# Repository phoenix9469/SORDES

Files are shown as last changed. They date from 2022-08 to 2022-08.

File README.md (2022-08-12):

## Sordes Motherboard SMT Version
### Schematic

### PCB

### 3D Top

### 3D Bottom

### Main MCU
ESP32_WROOM_32D
Internal Antenna
### Battery Charging
TP4056 Li-Ion Battery Charging Circuit(1A)
### DC-DC
SX1308 DC-DC Step Up Convertor(1.2MHz,2A)
3.7v~4.2v(Battery) to 5v(Logic)
### Weight measurement
HX711 24-Bit ADC for Weigh Scales
## Sordes LCD Board SMT Version
### Schematic

### PCB

### 3D Top
LCD_module_top
### 3D Bottom
LCD_module_bottom
### Main MCU
ESP32_WROOM_32D
Internal Antenna
### Pinmap
3.3V -> VCC  
GND -> GND  
GPIO15 -> CS  
GPIO4 -> RESET  
GPIO2 - > DC/RS  
GPIO23 -> SDI(MOSI),T_DIN  
GPIO18 -> SCK,T_CLK  
GPIO32 -> LED  
GPIO21 -> T_CS  
GPIO19 -> T_DO  
GPIO27 -> T_IRQ

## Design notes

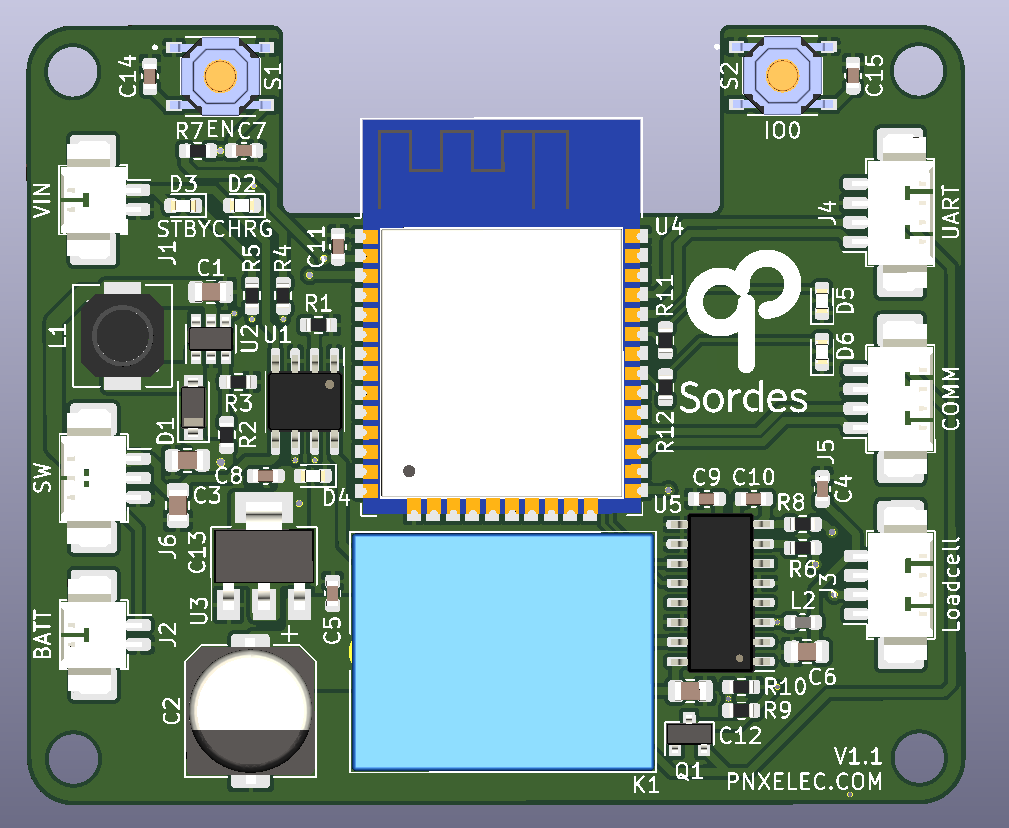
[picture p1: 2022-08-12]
Image/top.png

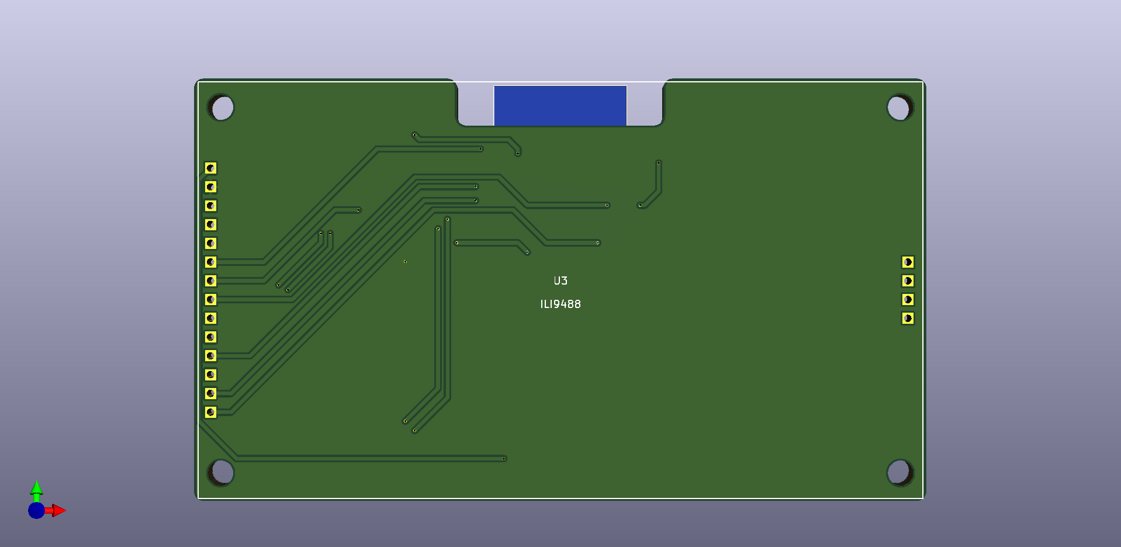
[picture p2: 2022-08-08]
Image/LCD_module_top.png

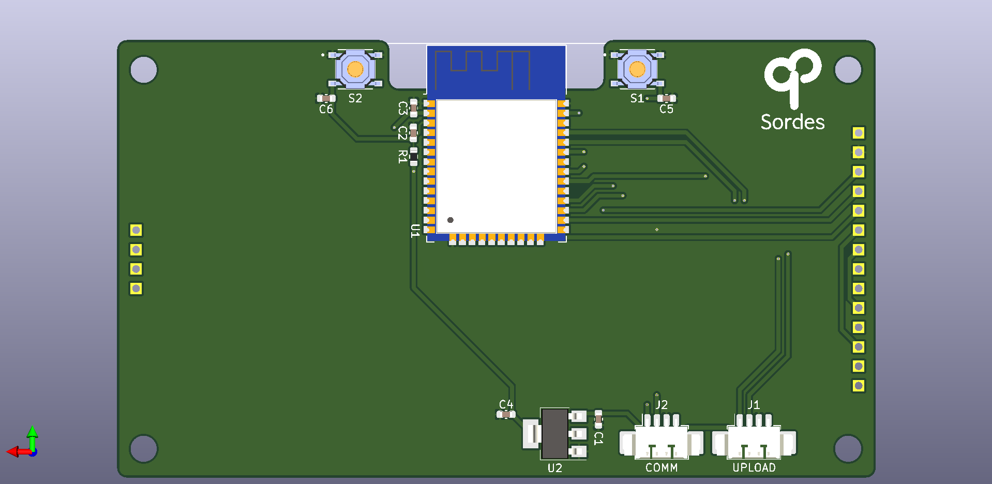
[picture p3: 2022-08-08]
Image/LCD_module_bottom.png

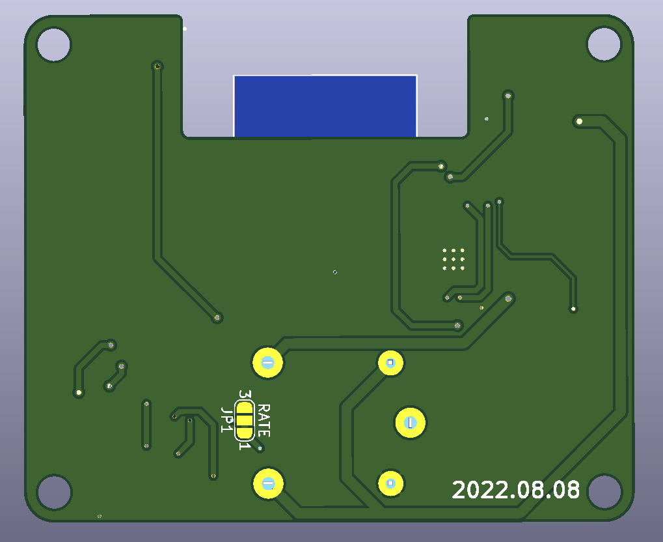
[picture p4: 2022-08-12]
Image/bottom.png

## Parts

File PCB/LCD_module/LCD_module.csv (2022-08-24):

Comment | Designator | Footprint | LCSC
100nf | C1,C2,C3,C4,C5,C6 | Capacitor_SMD:C_0603_1608Metric | C14663
UPLOAD | J1 | Connector_Molex:Molex_PicoBlade_53261-0471_1x04-1MP_P1.25mm_Horizontal | C240847
COMM | J2 | Connector_Molex:Molex_PicoBlade_53261-0471_1x04-1MP_P1.25mm_Horizontal | C240847
10k | R1 | Resistor_SMD:R_0603_1608Metric | C25804
IO0 | S1 | KIcad:SW_TS-1187A-B-A-B | C318884
EN | S2 | KIcad:SW_TS-1187A-B-A-B | C318884
ESP32-WROOM-32 | U1 | RF_Module:ESP32-WROOM-32 | C82899
AMS1117-3.3 | U2 | Package_TO_SOT_SMD:SOT-223-3_TabPin2 | C6186
ILI9488 | U3 | KIcad:ILI9488

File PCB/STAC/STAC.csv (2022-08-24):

Comment | Designator | Footprint | LCSC
22uf | C1,C3 | Capacitor_SMD:C_0805_2012Metric | C602037
10uf | C6,C12,C13 | Capacitor_SMD:C_0805_2012Metric | C15850
1000uf | C2 | Capacitor_SMD:CP_Elec_8x10 | C176671
100nf | C4,C5,C7,C8,C9,C10,C11,C14,C15 | Capacitor_SMD:C_0603_1608Metric | C14663
B0520LW | D1 | Diode_SMD:D_SOD-123 | C8570
CHRG | D2 | LED_SMD:LED_0603_1608Metric | C2286
STBY | D3 | LED_SMD:LED_0603_1608Metric | C2286
3.3v | D4 | LED_SMD:LED_0603_1608Metric | C2286
USER2 | D5 | LED_SMD:LED_0603_1608Metric | C2286
USER1 | D6 | LED_SMD:LED_0603_1608Metric | C2286
MountingHole | H1,H2,H3,H4 | MountingHole:MountingHole_3.2mm_M3
VIN | J1 | Connector_Molex:Molex_PicoBlade_53261-0271_1x02-1MP_P1.25mm_Horizontal | C189700
BATT | J2 | Connector_Molex:Molex_PicoBlade_53261-0271_1x02-1MP_P1.25mm_Horizontal | C189700
Loadcell | J3 | Connector_Molex:Molex_PicoBlade_53261-0471_1x04-1MP_P1.25mm_Horizontal | C240847
UART | J4 | Connector_Molex:Molex_PicoBlade_53261-0471_1x04-1MP_P1.25mm_Horizontal | C240847
COMM | J5 | Connector_Molex:Molex_PicoBlade_53261-0471_1x04-1MP_P1.25mm_Horizontal | C240847
SW | J6 | Connector_Molex:Molex_PicoBlade_53261-0371_1x03-1MP_P1.25mm_Horizontal | C293630
RATE | JP1 | Jumper:SolderJumper-3_P1.3mm_Bridged12_RoundedPad1.0x1.5mm_NumberLabels
POWER_SLCT | K1 | Relay_THT:Relay_SPDT_SANYOU_SRD_Series_Form_C
4.7uh | L1 | Inductor_SMD:L_6.3x6.3_H3 | C354606
3.3uh | L2 | Inductor_SMD:L_0603_1608Metric | C275346
MMBT4403 | Q1 | Package_TO_SOT_SMD:SOT-23 | C78864
1.2k | R1 | Resistor_SMD:R_0603_1608Metric | C22765
8.2k | R10 | Resistor_SMD:R_0603_1608Metric | C25981
330 | R11,R12 | Resistor_SMD:R_0603_1608Metric | C23138
47k | R2 | Resistor_SMD:R_0603_1608Metric | C25819
6.2k | R3 | Resistor_SMD:R_0603_1608Metric | C4260
1k | R4,R5 | Resistor_SMD:R_0603_1608Metric | C21190
100 | R6,R8 | Resistor_SMD:R_0603_1608Metric | C22775
10k | R7 | Resistor_SMD:R_0603_1608Metric | C25804
20k | R9 | Resistor_SMD:R_0603_1608Metric | C4184
EN | S1 | KIcad:SW_TS-1187A-B-A-B | C318884
IO0 | S2 | KIcad:SW_TS-1187A-B-A-B | C318884
TP4056 | U1 | Package_SO:SOIC-8-1EP_3.9x4.9mm_P1.27mm_EP2.29x3mm_ThermalVias | C382139
SX1308 | U2 | Package_TO_SOT_SMD:SOT-23-6 | C78162
AMS1117-3.3 | U3 | Package_TO_SOT_SMD:SOT-223-3_TabPin2 | C6186
ESP32-WROOM-32D | U4 | RF_Module:ESP32-WROOM-32 | C82899
HX711 | U5 | Package_SO:SO-16_3.9x9.9mm_P1.27mm | C43656

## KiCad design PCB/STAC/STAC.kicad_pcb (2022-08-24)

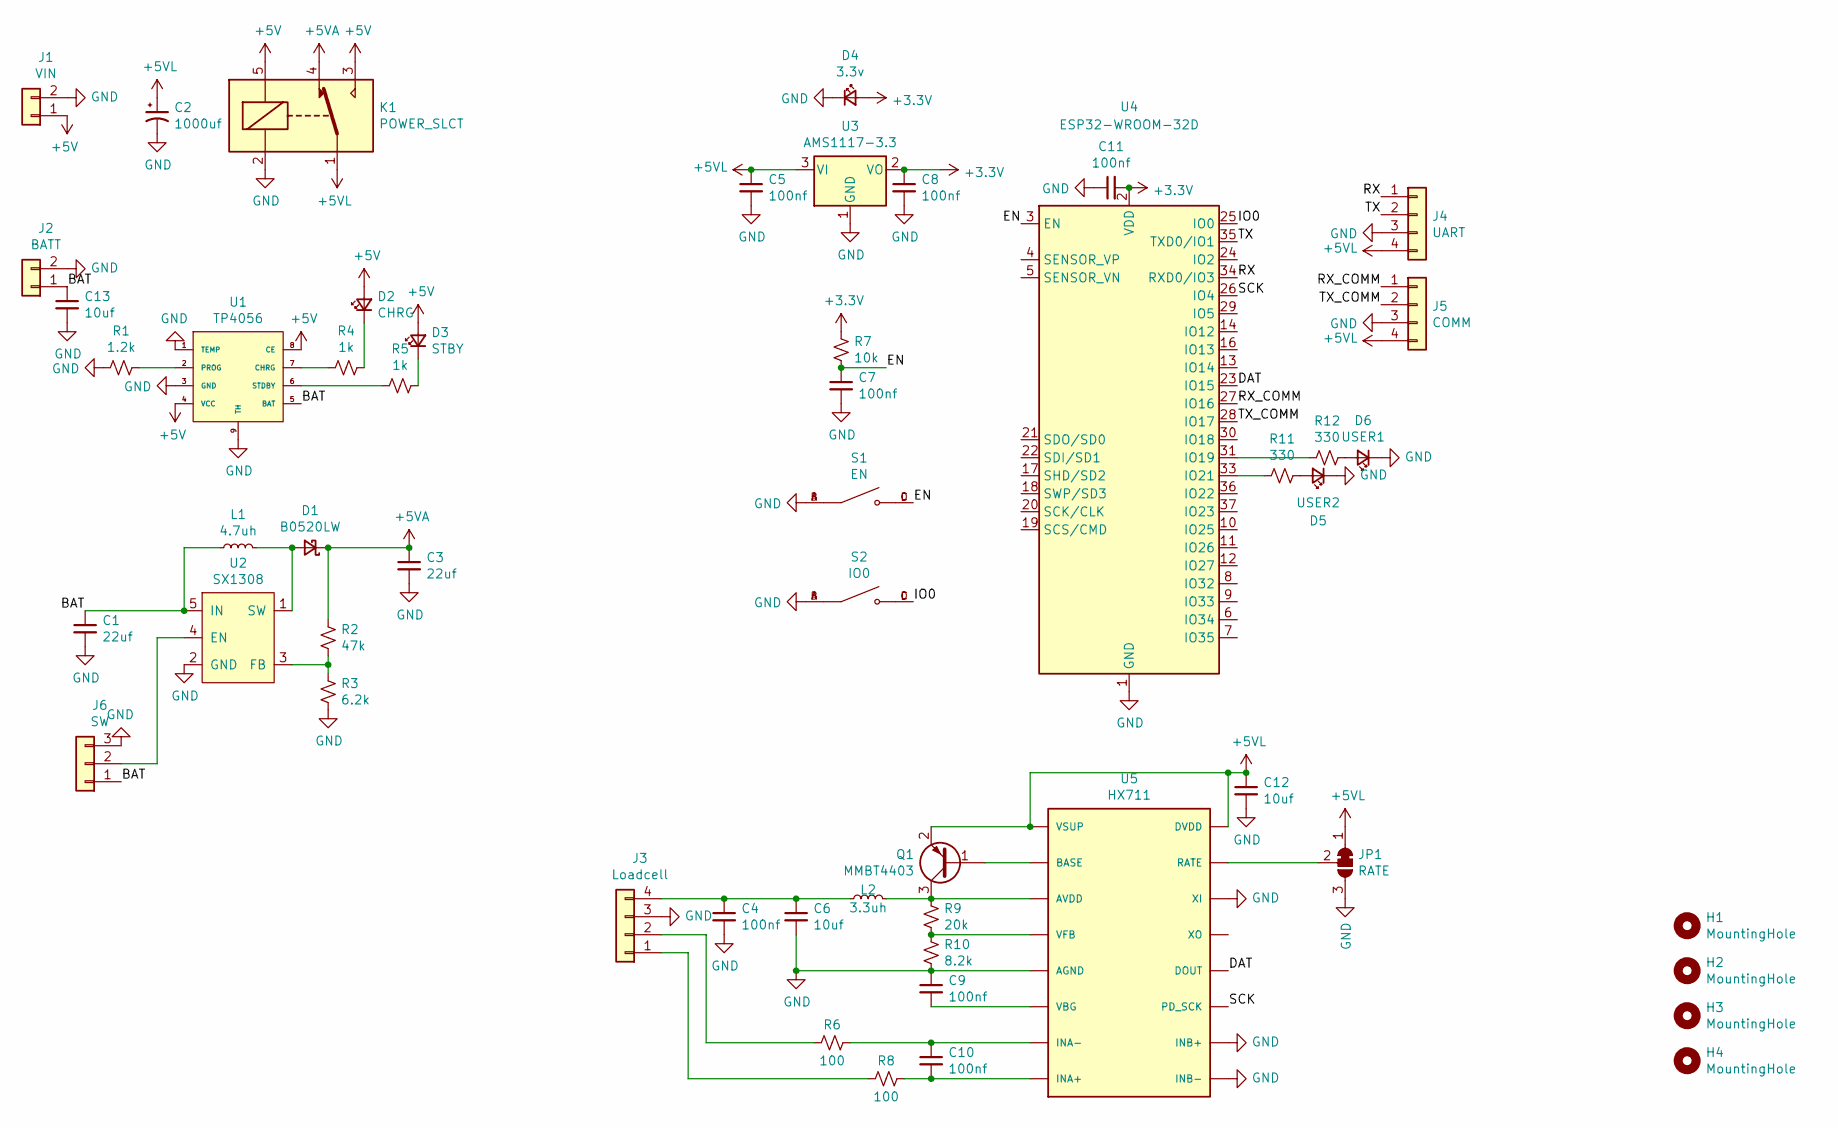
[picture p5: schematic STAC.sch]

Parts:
C1, C3: 22uf; C_0805_2012Metric
C2: 1000uf; CP_Elec_8x10
C4, C5, C7, C8, C9, C10, C11: 100nf; C_0603_1608Metric
C6, C12, C13: 10uf; C_0805_2012Metric
D1: B0520LW; D_SOD-123
D2: CHRG; LED_0603_1608Metric
D3: STBY; LED_0603_1608Metric
D4: 3.3v; LED_0603_1608Metric
D5: USER2; LED_0603_1608Metric
D6: USER1; LED_0603_1608Metric
H1, H2, H3, H4: MountingHole; MountingHole_3.2mm_M3
J1: VIN; Molex_PicoBlade_53261-0271_1x02-1MP_P1.25mm_Horizontal
J2: BATT; Molex_PicoBlade_53261-0271_1x02-1MP_P1.25mm_Horizontal
J3: Loadcell; Molex_PicoBlade_53261-0471_1x04-1MP_P1.25mm_Horizontal
J4: UART; Molex_PicoBlade_53261-0471_1x04-1MP_P1.25mm_Horizontal
J5: COMM; Molex_PicoBlade_53261-0471_1x04-1MP_P1.25mm_Horizontal
J6: SW; Molex_PicoBlade_53261-0371_1x03-1MP_P1.25mm_Horizontal
JP1: RATE; SolderJumper-3_P1.3mm_Bridged12_RoundedPad1.0x1.5mm_NumberL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
K1: POWER_SLCT; Relay_SPDT_SANYOU_SRD_Series_Form_C
L1: 4.7uh; L_6.3x6.3_H3
L2: 3.3uh; L_0603_1608Metric
Q1: MMBT4403; SOT-23
R1: 1.2k; R_0603_1608Metric
R2: 47k; R_0603_1608Metric
R3: 6.2k; R_0603_1608Metric
R4, R5: 1k; R_0603_1608Metric
R6, R8: 100; R_0603_1608Metric
R7: 10k; R_0603_1608Metric
R9: 20k; R_0603_1608Metric
R10: 8.2k; R_0603_1608Metric
R11, R12: 330; R_0603_1608Metric
S1: EN; SW_TS-1187A-B-A-B; PARTREV A0
S2: IO0; SW_TS-1187A-B-A-B; PARTREV A0
U1: TP4056; SOIC-8-1EP_3.9x4.9mm_P1.27mm_EP2.29x3mm_ThermalVias
U2: SX1308; SOT-23-6
U3: AMS1117-3.3; SOT-223-3_TabPin2
U4: ESP32-WROOM-32D; ESP32-WROOM-32
U5: HX711; SO-16_3.9x9.9mm_P1.27mm

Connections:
+3V3: C8.1, C11.2, D4.2 (A), R7.1, U3.2 (VO), U4.2 (VDD)
+5V: D2.2 (A), D3.2 (A), J1.1, K1.3, K1.5, U1.4 (VCC), U1.8 (CE)
+5VA: C3.1, D1.1 (K), K1.4, R2.1
+5VL: C2.1, C5.1, C12.1, J4.4, J5.4, JP1.1 (A), K1.1, Q1.2 (E), U3.3 (VI), U5.1 (VSUP), U5.16 (DVDD)
/BAT: C1.1, C13.1, J2.1, J6.1, L1.1, U1.5 (BAT), U2.5 (IN)
/DAT: U4.23 (IO15), U5.12 (DOUT)
/EN: C7.1, R7.2, S1.C, S1.D, U4.3 (EN)
/IO0: S2.C, S2.D, U4.25 (IO0)
/RX: J4.1, U4.34 (RXD0/IO3)
/RX_COMM: J5.1, U4.27 (IO16)
/SCK: U4.26 (IO4), U5.11 (PD_SCK)
/TX: J4.2, U4.35 (TXD0/IO1)
/TX_COMM: J5.2, U4.28 (IO17)
GND: C1.2, C2.2, C3.2, C4.2, C5.2, C6.2, C7.2, C8.2, C9.1, C11.1, C12.2, C13.2, D4.1 (K), D5.1 (K), D6.1 (K), J1.2, J2.2, J3.3, J4.3, J5.3, J6.3, JP1.3 (B), K1.2, R1.2, R3.2, R10.2, S1.A, S1.B, S2.A, S2.B, U1.1 (TEMP), U1.3 (GND), U1.9 (TH), U2.2 (GND), U3.1 (GND), U4.1 (GND), U4.15 (GND), U4.38 (GND), U4.39 (GND), U5.5 (AGND), U5.9 (INB-), U5.10 (INB+), U5.14 (XI)
unnamed: C4.1, C6.1, J3.4, L2.1
unnamed: C9.2, U5.6 (VBG)
unnamed: C10.1, R6.1, U5.7 (INA-)
unnamed: C10.2, R8.1, U5.8 (INA+)
unnamed: D1.2 (A), L1.2, U2.1 (SW)
unnamed: D2.1 (K), R4.1
unnamed: D3.1 (K), R5.1
unnamed: D5.2 (A), R11.1
unnamed: D6.2 (A), R12.1
unnamed: J3.1, R8.2
unnamed: J3.2, R6.2
unnamed: J6.2, U2.4 (EN)
unnamed: JP1.2 (C), U5.15 (RATE)
unnamed: L2.2, Q1.3 (C), R9.1, U5.3 (AVDD)
unnamed: Q1.1 (B), U5.2 (BASE)
unnamed: R1.1, U1.2 (PROG)
unnamed: R2.2, R3.1, U2.3 (FB)
unnamed: R4.2, U1.7 (CHRG)
unnamed: R5.2, U1.6 (STDBY)
unnamed: R9.2, R10.1, U5.4 (VFB)
unnamed: R11.2, U4.33 (IO21)
unnamed: R12.2, U4.31 (IO19)

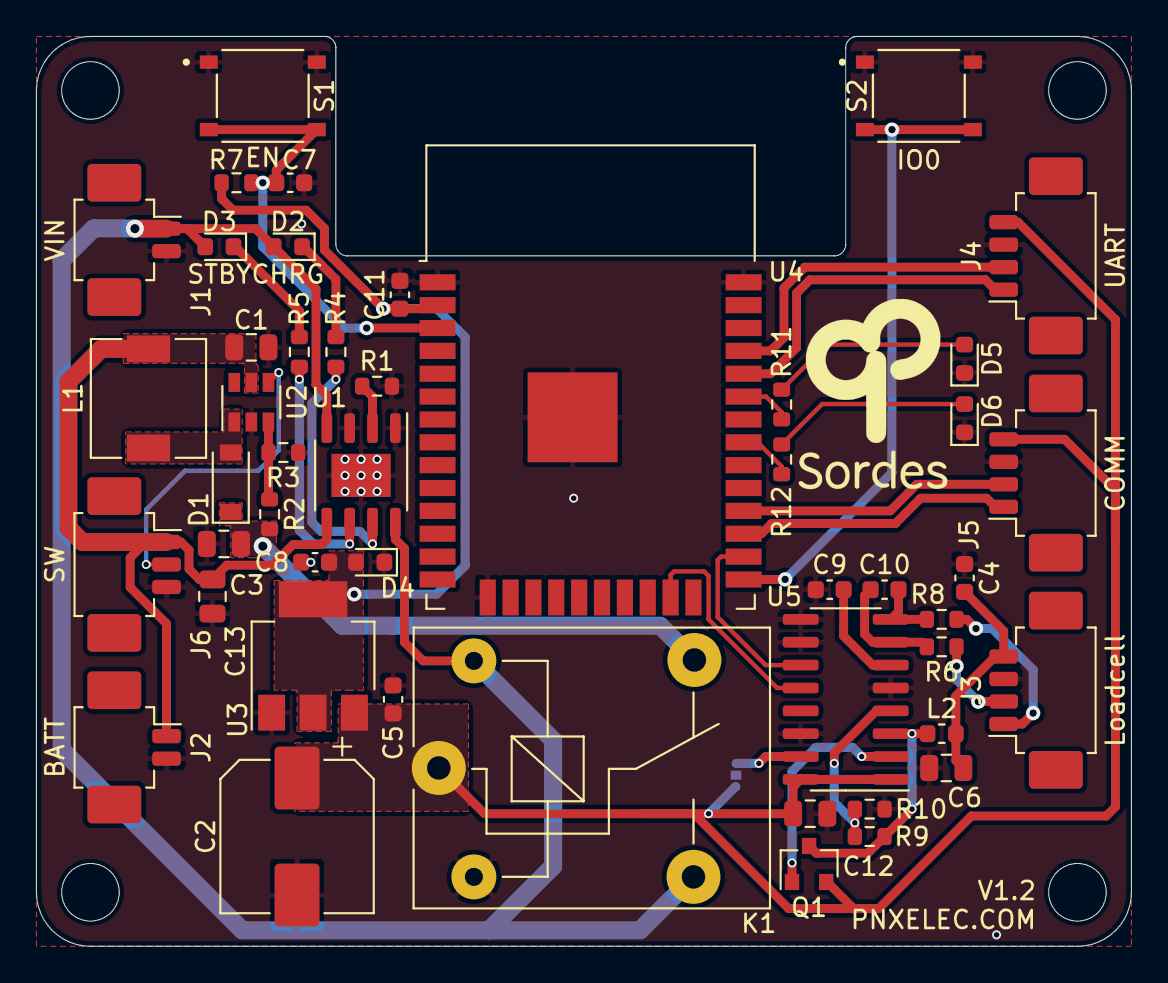
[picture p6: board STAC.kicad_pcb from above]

Board: 2 copper layers, 60.8 x 50.5 mm, 53 parts (1 on the bottom side), 36 nets.

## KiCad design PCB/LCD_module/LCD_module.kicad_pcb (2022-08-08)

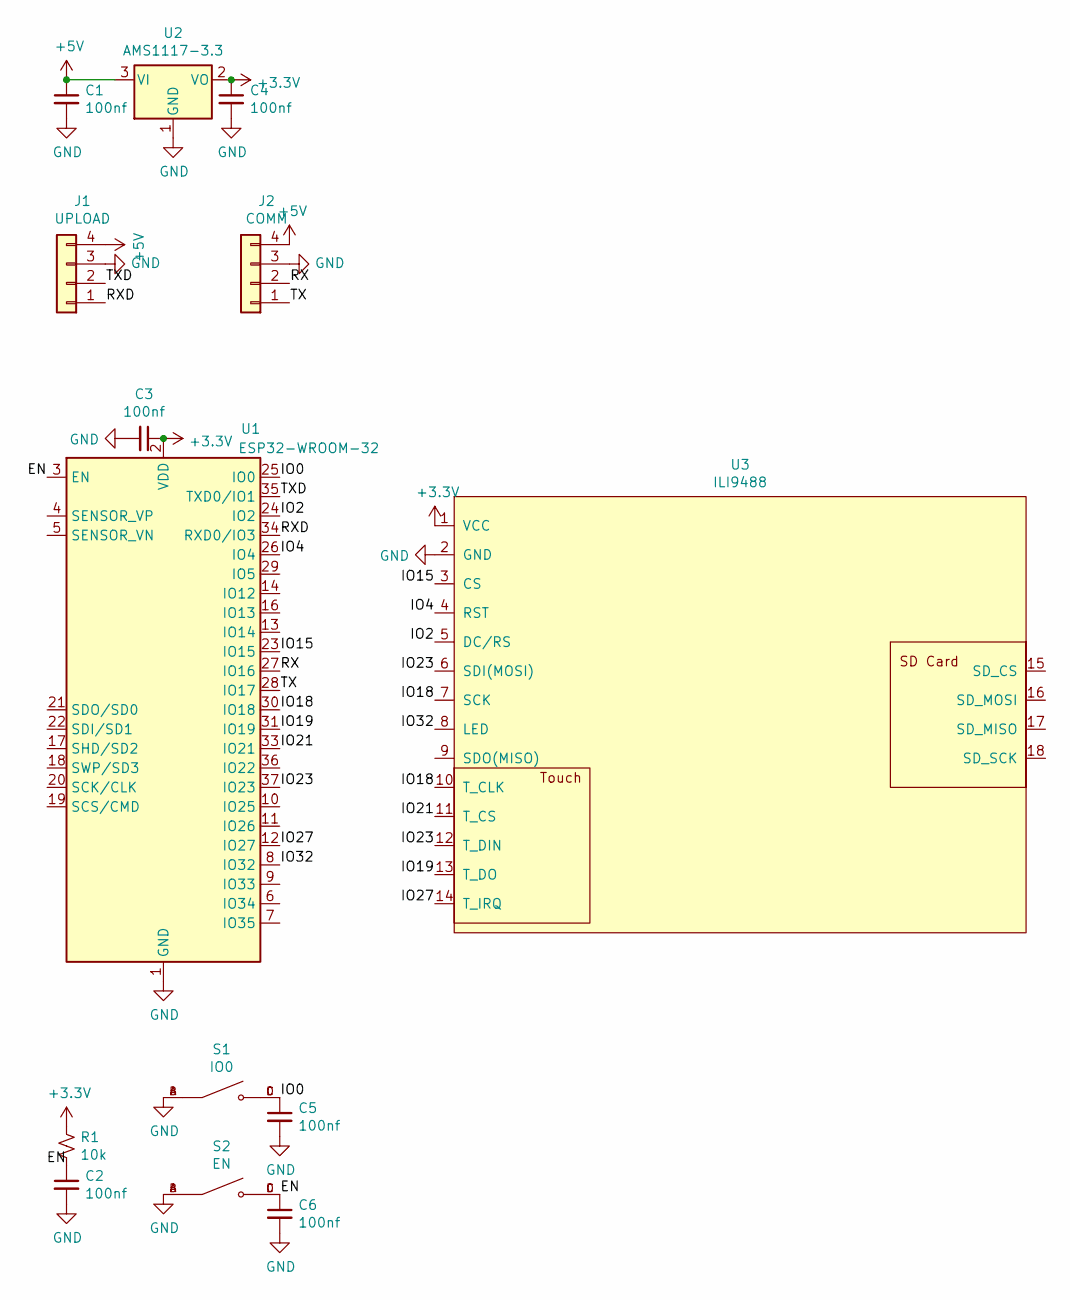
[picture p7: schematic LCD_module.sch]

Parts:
C1, C2, C3, C4, C5, C6: 100nf; C_0603_1608Metric
J1: UPLOAD; Molex_PicoBlade_53261-0471_1x04-1MP_P1.25mm_Horizontal
J2: COMM; Molex_PicoBlade_53261-0471_1x04-1MP_P1.25mm_Horizontal
R1: 10k; R_0603_1608Metric
S1: IO0; SW_TS-1187A-B-A-B; PARTREV A0
S2: EN; SW_TS-1187A-B-A-B; PARTREV A0
U1: ESP32-WROOM-32
U2: AMS1117-3.3; SOT-223-3_TabPin2
U3: ILI9488

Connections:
+3V3: C3.1, C4.1, R1.1, U1.2 (VDD), U2.2 (VO), U3.1 (VCC)
+5V: C1.1, J1.4, J2.4, U2.3 (VI)
/EN: C2.1, C6.1, R1.2, S2.C, S2.D, U1.3 (EN)
/IO0: C5.1, S1.C, S1.D, U1.25 (IO0)
/IO2: U1.24 (IO2), U3.5 (DC/RS)
/IO4: U1.26 (IO4), U3.4 (RST)
/IO15: U1.23 (IO15), U3.3 (CS)
/IO18: U1.30 (IO18), U3.7 (SCK), U3.10 (T_CLK)
/IO19: U1.31 (IO19), U3.13 (T_DO)
/IO21: U1.33 (IO21), U3.11 (T_CS)
/IO23: U1.37 (IO23), U3.6 (SDI(MOSI)), U3.12 (T_DIN)
/IO27: U1.12 (IO27), U3.14 (T_IRQ)
/IO32: U1.8 (IO32), U3.8 (LED)
/RX: J2.2, U1.27 (IO16)
/RXD: J1.1, U1.34 (RXD0/IO3)
/TX: J2.1, U1.28 (IO17)
/TXD: J1.2, U1.35 (TXD0/IO1)
GND: C1.2, C2.2, C3.2, C4.2, C5.2, C6.2, J1.3, J2.3, S1.A, S1.B, S2.A, S2.B, U1.1 (GND), U1.15 (GND), U1.38 (GND), U1.39 (GND), U2.1 (GND), U3.2 (GND)

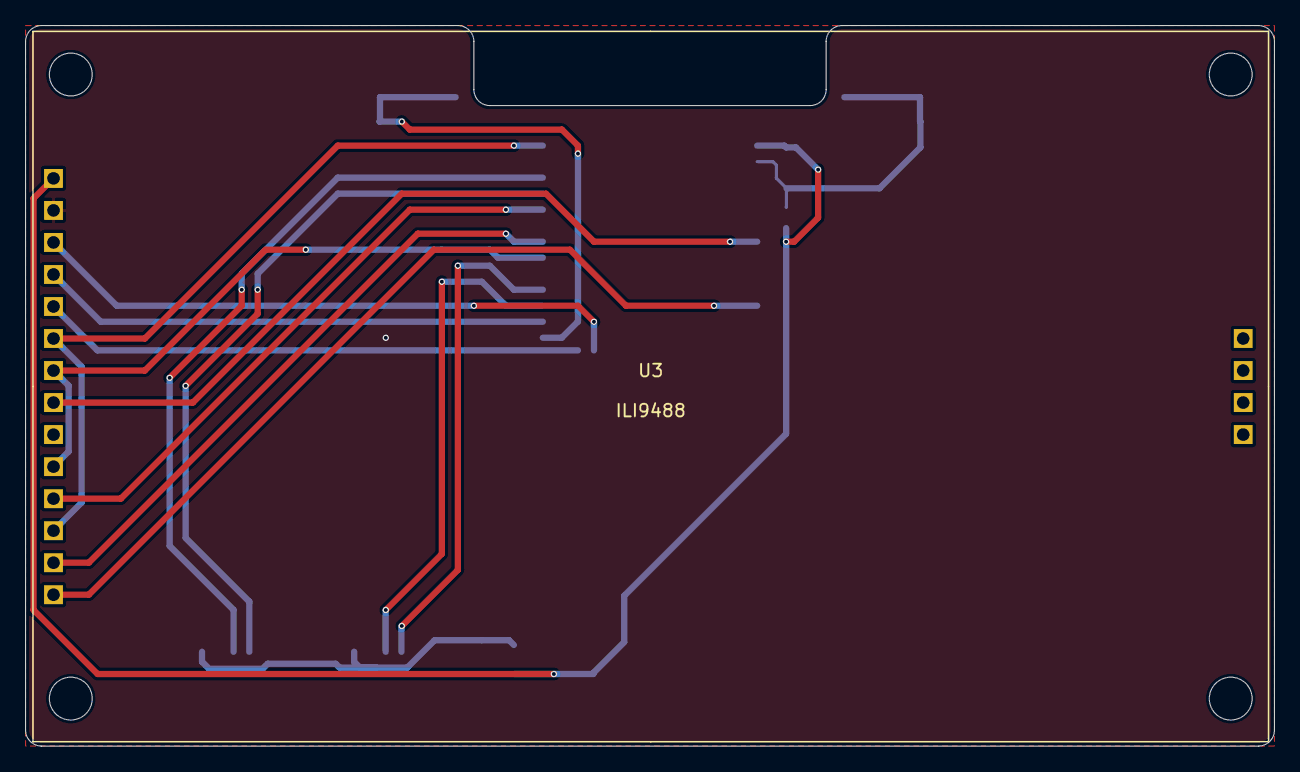
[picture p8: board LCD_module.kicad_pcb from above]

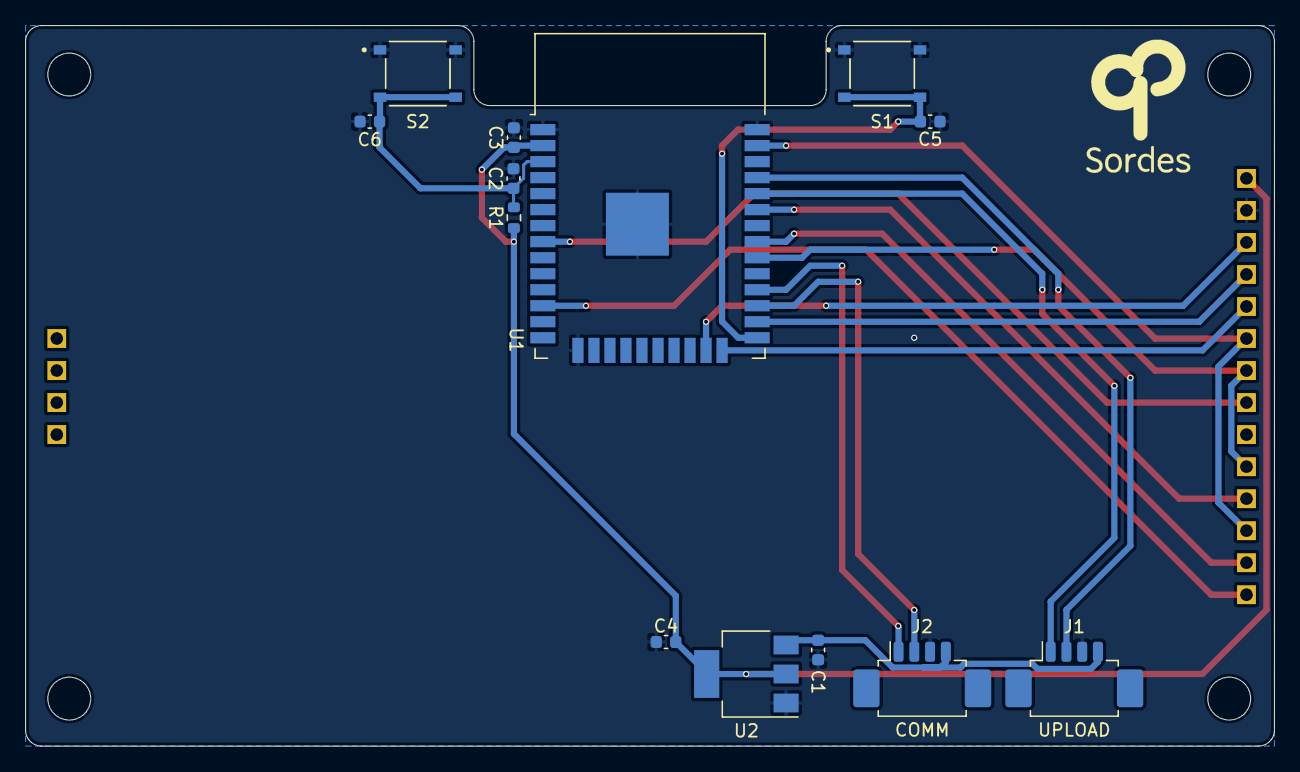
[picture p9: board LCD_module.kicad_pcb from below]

Board: 2 copper layers, 99.1 x 57.1 mm, 14 parts (13 on the bottom side), 18 nets.

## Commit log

2022-08-12 image update
    [STAC-B_Cu.gbr, STAC-B_Mask.gbr, STAC-B_Paste.gbr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]
2022-08-24 CIrcuit changed
    [LCD_module.csv, STAC.csv, STAC.kicad_pcb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]
